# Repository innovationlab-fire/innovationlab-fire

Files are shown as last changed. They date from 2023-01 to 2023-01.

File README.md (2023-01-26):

For more detailed information about this project visit our website: https://innovationlab-fire.netlify.app

**Installation guide:**

1) To reconstruct the prototype, you need the materials listed in the following:

- Arduino R3 incl. USB-cabel
- MQ-2 Gas Sensor
- SPI Reader Micro Memory SD TF Card Memory Card Shield Module
- SIM800L GPRS GSM Module incl. antenna
- SD-Card
- Lithium Polymer Battery 3.7 V 2000 mAh
- Breadboard with 830 or 400 pins
- Sim-Card
- A Case for the hardware	(files for 3d-print available in repository)	

In addition, for the installation you need jumper wires, resistors (330 Ohm) and a soldering device. All in all, you should expect spending approximately 60 to 70 euros for the purchase of all materials for one device (as of January 2023).

2) After collecting all needed materials, you have to download the Arduino IDE. You can do that directly on the Arduino website. After successfully downloading the IDE you should also download the required library “Adafruit BusIO” by Adafruit via the integrated library manager on your Arduino IDE. Then, you can download the project code from our Github Repository.

3) After downloading the code, start your Arduino IDE and click on „File“ in the top left corner of the Arduino IDE and click on „Open…“. Then, you need to select the previously downloaded code and it will be opened in the IDE. Now, you only have to make a small alteration to the code, in order to send the SMS to the right phone number regarding your respective use case (we have made a comment like “XXXXX” to indicate where you have to change the number). After that, the code is ready to use.

4) Before starting with the hardware, create an empty csv file called "test.csv" on your SD card. This will be used later in order to save the measured gas values including the respective timestamps.

5) Regarding the hardware, you need to wire up the Arduino uno and the modules like shown in the hardware diagram below.

Circuit-diagram-SEDI

You also need to solder the sim module correctly, connect it to the separate LiPo battery and clip on the green antenna. After you have done this, see if the sim module is working correctly if it flashes every 3 seconds. If it only flashes at 1 second intervals, the sim module is still searching for the available network. As a starting aid, you can find a video concerning the wiring and soldering on our Youtube chanel: https://www.youtube.com/channel/UCS5Bbf_3bhYVp7_8QDcPbxg. Please note that the Arduino requires a constant power supply for smooth operation (5V), which can be connected via the power supply unit. Please bear in mind that we only describe the start-up via a computer, which, however, is not a realistic option for the desired application in a forest. Therefore, please inquire about alternative power supply options.

6) Once the hardware is wired and soldered correctly, you can connect the Arduino with the USB cable to the computer. Click on the „Upload“ button in the toolbar of the IDE and the code will be uploaded to the Arduino. The code will then start running and you can open the serial monitor to track the process.

7) After the code was once uploaded to the Arduino through the IDE, the Arduino will always start running the code once it has a power supply. Therefore, you can choose alternative power supply methods other than plugging it into the computer as described above.

8) In case of high gas values in the air, the device sends an SMS to the phone number you have specified. In addition, the measured values are stored on the SD card and you can visualize them by inserting the SD card into your computer via Excel according to your wishes.

**Licenses**

Our project is published under the GNU GENERAL PUBLIC LICENSE version 3 license. The full source code of the project is available on our GitHub page.

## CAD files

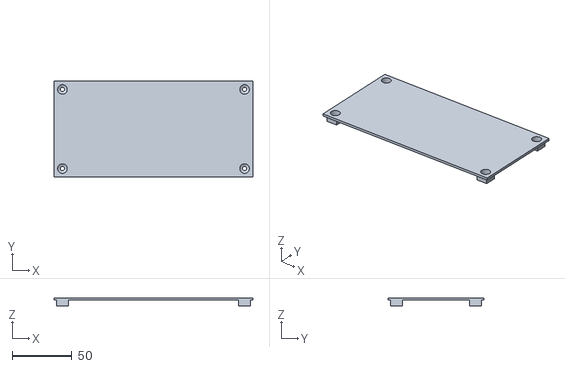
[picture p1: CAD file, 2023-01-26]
3D-Files Case/lid.stl
166.0 x 80.0 x 7.00

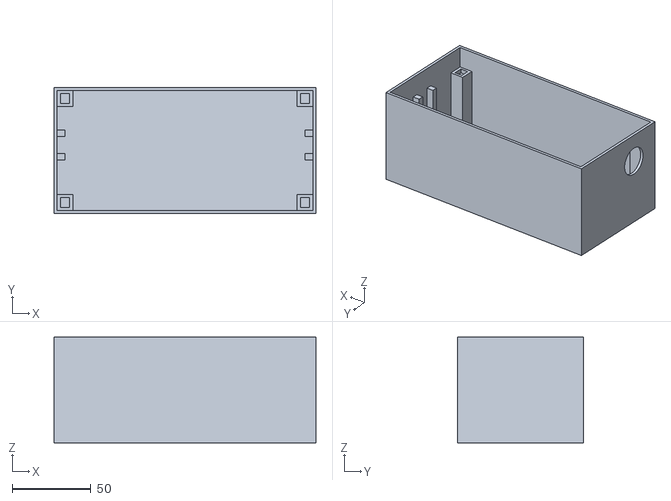
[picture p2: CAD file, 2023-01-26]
3D-Files Case/case.stl
166.0 x 80.0 x 67.0

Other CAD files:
3D-Files Case/case.ipt
3D-Files Case/lid.ipt

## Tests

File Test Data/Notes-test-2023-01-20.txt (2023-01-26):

13:40 fire start, standing close to it, only gasoline burning
13:50 close to it (1 meter), value at over 100
13:56 10 meters distance
13:59 fire is made bigger
wood burns
14:13 fire smokes, distance 3-4 m (directly at smoke value of 100 not at smoke 70-75)
14:18 1m distance
14:19 1m distance (values from 120-130)
14:22 20m distance
14:23 3m distance
14:24 1m
14:25 5m
14:27 1m
14:28 10 m
14:35-14:36 10 m
14:39 2 m
14:45 extinguishing action

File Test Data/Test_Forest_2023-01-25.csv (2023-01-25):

Date | Time | SensorValue
 | 37
23/01/25 | 16:01:04+04 | 36
23/01/25 | 16:01:08+04 | 36
23/01/25 | 16:01:11+04 | 36
23/01/25 | 16:01:14+04 | 35
23/01/25 | 16:01:18+04 | 35
23/01/25 | 16:01:21+04 | 35
23/01/25 | 16:01:24+04 | 34
23/01/25 | 16:01:28+04 | 34
23/01/25 | 16:01:31+04 | 34
23/01/25 | 16:01:34+04 | 34
23/01/25 | 16:01:38+04 | 34
23/01/25 | 16:01:41+04 | 34
23/01/25 | 16:01:45+04 | 34
23/01/25 | 16:01:48+04 | 34
23/01/25 | 16:01:51+04 | 33
23/01/25 | 16:01:55+04 | 33
23/01/25 | 16:01:58+04 | 33
23/01/25 | 16:02:01+04 | 33
23/01/25 | 16:02:05+04 | 33
23/01/25 | 16:02:08+04 | 33
23/01/25 | 16:02:11+04 | 33
23/01/25 | 16:02:15+04 | 33
23/01/25 | 16:02:18+04 | 32
23/01/25 | 16:02:21+04 | 32
23/01/25 | 16:02:25+04 | 32
23/01/25 | 16:02:28+04 | 32
23/01/25 | 16:02:31+04 | 32
23/01/25 | 16:02:35+04 | 32
23/01/25 | 16:02:38+04 | 32
23/01/25 | 16:02:41+04 | 32
23/01/25 | 16:02:45+04 | 32
23/01/25 | 16:02:48+04 | 32
23/01/25 | 16:02:51+04 | 32
23/01/25 | 16:02:55+04 | 32
23/01/25 | 16:02:58+04 | 32
23/01/25 | 16:03:01+04 | 32
23/01/25 | 16:03:05+04 | 32
23/01/25 | 16:03:08+04 | 32
23/01/25 | 16:03:11+04 | 32
23/01/25 | 16:03:15+04 | 32
23/01/25 | 16:03:18+04 | 32
23/01/25 | 16:03:22+04 | 31
23/01/25 | 16:03:25+04 | 32
23/01/25 | 16:03:28+04 | 32
23/01/25 | 16:03:32+04 | 32
23/01/25 | 16:03:35+04 | 32
23/01/25 | 16:03:38+04 | 31
23/01/25 | 16:03:42+04 | 31
23/01/25 | 16:03:45+04 | 32
23/01/25 | 16:03:48+04 | 31
23/01/25 | 16:03:52+04 | 31
23/01/25 | 16:03:55+04 | 31
23/01/25 | 16:03:58+04 | 31
23/01/25 | 16:04:02+04 | 31
23/01/25 | 16:04:05+04 | 31
23/01/25 | 16:04:08+04 | 31
23/01/25 | 16:04:12+04 | 31
23/01/25 | 16:04:15+04 | 31
23/01/25 | 16:04:19+04 | 31
23/01/25 | 16:04:22+04 | 31
23/01/25 | 16:04:25+04 | 31
23/01/25 | 16:04:29+04 | 31
23/01/25 | 16:04:32+04 | 31
23/01/25 | 16:04:35+04 | 31
23/01/25 | 16:04:39+04 | 31
23/01/25 | 16:04:42+04 | 31
23/01/25 | 16:04:45+04 | 31
23/01/25 | 16:04:49+04 | 31
23/01/25 | 16:04:52+04 | 31
23/01/25 | 16:04:55+04 | 31
23/01/25 | 16:04:59+04 | 31
23/01/25 | 16:05:02+04 | 31
23/01/25 | 16:05:05+04 | 31
23/01/25 | 16:05:09+04 | 31
23/01/25 | 16:05:12+04 | 31
23/01/25 | 16:05:15+04 | 31
23/01/25 | 16:05:19+04 | 31
23/01/25 | 16:05:22+04 | 31
23/01/25 | 16:05:25+04 | 31
23/01/25 | 16:05:29+04 | 31
23/01/25 | 16:05:32+04 | 31
23/01/25 | 16:05:35+04 | 31
23/01/25 | 16:05:39+04 | 31
23/01/25 | 16:05:42+04 | 31
23/01/25 | 16:05:45+04 | 31
23/01/25 | 16:05:49+04 | 31
23/01/25 | 16:05:52+04 | 31
23/01/25 | 16:05:56+04 | 31
23/01/25 | 16:05:59+04 | 31
23/01/25 | 16:06:02+04 | 31
23/01/25 | 16:06:06+04 | 31
23/01/25 | 16:06:09+04 | 31
23/01/25 | 16:06:12+04 | 31
23/01/25 | 16:06:16+04 | 30
23/01/25 | 16:06:19+04 | 31
23/01/25 | 16:06:22+04 | 31
23/01/25 | 16:06:26+04 | 31
23/01/25 | 16:06:29+04 | 30
23/01/25 | 16:06:32+04 | 30
23/01/25 | 16:06:36+04 | 31
23/01/25 | 16:06:39+04 | 31
23/01/25 | 16:06:42+04 | 31
23/01/25 | 16:06:46+04 | 31
23/01/25 | 16:06:49+04 | 31
23/01/25 | 16:06:52+04 | 31
23/01/25 | 16:06:56+04 | 31
23/01/25 | 16:06:59+04 | 31
23/01/25 | 16:07:02+04 | 31
23/01/25 | 16:07:06+04 | 30
23/01/25 | 16:07:09+04 | 31
23/01/25 | 16:07:12+04 | 31
23/01/25 | 16:07:16+04 | 31
23/01/25 | 16:07:19+04 | 31
23/01/25 | 16:07:22+04 | 31
23/01/25 | 16:07:26+04 | 31
23/01/25 | 16:07:29+04 | 31
23/01/25 | 16:07:32+04 | 31
23/01/25 | 16:07:36+04 | 31
23/01/25 | 16:07:39+04 | 31
23/01/25 | 16:07:43+04 | 31
23/01/25 | 16:07:46+04 | 31
23/01/25 | 16:07:49+04 | 31
23/01/25 | 16:07:53+04 | 31
23/01/25 | 16:07:56+04 | 31
23/01/25 | 16:07:59+04 | 30
23/01/25 | 16:08:03+04 | 31
23/01/25 | 16:08:06+04 | 30
23/01/25 | 16:08:09+04 | 31
23/01/25 | 16:08:13+04 | 31
23/01/25 | 16:08:16+04 | 30
23/01/25 | 16:08:19+04 | 31
23/01/25 | 16:08:23+04 | 30
23/01/25 | 16:08:26+04 | 31
23/01/25 | 16:08:29+04 | 31
23/01/25 | 16:08:33+04 | 30
23/01/25 | 16:08:36+04 | 31
23/01/25 | 16:08:39+04 | 31
23/01/25 | 16:08:43+04 | 30
23/01/25 | 16:08:46+04 | 30
23/01/25 | 16:08:49+04 | 30
23/01/25 | 16:08:53+04 | 30
23/01/25 | 16:08:56+04 | 30
23/01/25 | 16:08:59+04 | 31
23/01/25 | 16:09:03+04 | 31
23/01/25 | 16:09:06+04 | 31
23/01/25 | 16:09:10+04 | 30
23/01/25 | 16:09:13+04 | 30
23/01/25 | 16:09:16+04 | 30
23/01/25 | 16:09:20+04 | 30
23/01/25 | 16:09:23+04 | 31
23/01/25 | 16:09:26+04 | 30
23/01/25 | 16:09:30+04 | 30
23/01/25 | 16:09:33+04 | 31
23/01/25 | 16:09:36+04 | 31
23/01/25 | 16:09:40+04 | 30
23/01/25 | 16:09:43+04 | 31
23/01/25 | 16:09:46+04 | 31
23/01/25 | 16:09:50+04 | 31
23/01/25 | 16:09:53+04 | 31
23/01/25 | 16:09:56+04 | 31
23/01/25 | 16:10:00+04 | 31
23/01/25 | 16:10:03+04 | 31
23/01/25 | 16:10:06+04 | 31
23/01/25 | 16:10:10+04 | 31
23/01/25 | 16:10:13+04 | 31
23/01/25 | 16:10:16+04 | 31
23/01/25 | 16:10:20+04 | 30
23/01/25 | 16:10:23+04 | 30
23/01/25 | 16:10:26+04 | 31
23/01/25 | 16:10:30+04 | 30
23/01/25 | 16:10:33+04 | 30
23/01/25 | 16:10:36+04 | 30
23/01/25 | 16:10:40+04 | 30
23/01/25 | 16:10:43+04 | 31
23/01/25 | 16:10:46+04 | 30
23/01/25 | 16:10:50+04 | 31
23/01/25 | 16:10:53+04 | 30
23/01/25 | 16:10:57+04 | 31
23/01/25 | 16:11:00+04 | 30
23/01/25 | 16:11:03+04 | 30
23/01/25 | 16:11:07+04 | 30
23/01/25 | 16:11:10+04 | 30
23/01/25 | 16:11:13+04 | 30
23/01/25 | 16:11:17+04 | 30
23/01/25 | 16:11:20+04 | 30
23/01/25 | 16:11:23+04 | 30
23/01/25 | 16:11:27+04 | 30
23/01/25 | 16:11:30+04 | 30
23/01/25 | 16:11:33+04 | 31
23/01/25 | 16:11:37+04 | 30
23/01/25 | 16:11:40+04 | 30
23/01/25 | 16:11:43+04 | 30
23/01/25 | 16:11:47+04 | 30
23/01/25 | 16:11:50+04 | 30
23/01/25 | 16:11:53+04 | 30
23/01/25 | 16:11:57+04 | 30
23/01/25 | 16:12:00+04 | 30
23/01/25 | 16:12:03+04 | 30
23/01/25 | 16:12:07+04 | 30
23/01/25 | 16:12:10+04 | 30
23/01/25 | 16:12:13+04 | 30
23/01/25 | 16:12:17+04 | 30
23/01/25 | 16:12:20+04 | 30
23/01/25 | 16:12:24+04 | 30
23/01/25 | 16:12:27+04 | 30
23/01/25 | 16:12:30+04 | 30
23/01/25 | 16:12:34+04 | 30
23/01/25 | 16:12:37+04 | 30
23/01/25 | 16:12:40+04 | 30
23/01/25 | 16:12:44+04 | 30
23/01/25 | 16:12:47+04 | 30
23/01/25 | 16:12:50+04 | 30
23/01/25 | 16:12:54+04 | 30
23/01/25 | 16:12:57+04 | 30
23/01/25 | 16:13:00+04 | 31
23/01/25 | 16:13:04+04 | 30
23/01/25 | 16:13:07+04 | 30
23/01/25 | 16:13:10+04 | 31
23/01/25 | 16:13:14+04 | 30
23/01/25 | 16:13:17+04 | 30
23/01/25 | 16:13:20+04 | 30
23/01/25 | 16:13:24+04 | 30
23/01/25 | 16:13:27+04 | 30
23/01/25 | 16:13:30+04 | 30
23/01/25 | 16:13:34+04 | 30
23/01/25 | 16:13:37+04 | 30
23/01/25 | 16:13:40+04 | 30
23/01/25 | 16:13:44+04 | 30
23/01/25 | 16:13:47+04 | 30
23/01/25 | 16:13:50+04 | 30
23/01/25 | 16:13:54+04 | 30
23/01/25 | 16:13:57+04 | 30
23/01/25 | 16:14:00+04 | 30
23/01/25 | 16:14:04+04 | 30
23/01/25 | 16:14:07+04 | 30
23/01/25 | 16:14:11+04 | 30
23/01/25 | 16:14:14+04 | 30
23/01/25 | 16:14:17+04 | 30
23/01/25 | 16:14:21+04 | 30
23/01/25 | 16:14:24+04 | 30
23/01/25 | 16:14:27+04 | 30
23/01/25 | 16:14:31+04 | 30
23/01/25 | 16:14:34+04 | 30
23/01/25 | 16:14:37+04 | 30
23/01/25 | 16:14:41+04 | 30
23/01/25 | 16:14:44+04 | 30
23/01/25 | 16:14:47+04 | 30
23/01/25 | 16:14:51+04 | 30
23/01/25 | 16:14:54+04 | 30
23/01/25 | 16:14:57+04 | 30
23/01/25 | 16:15:01+04 | 30
23/01/25 | 16:15:04+04 | 30
23/01/25 | 16:15:07+04 | 30
23/01/25 | 16:15:11+04 | 30
23/01/25 | 16:15:14+04 | 30
23/01/25 | 16:15:17+04 | 30
23/01/25 | 16:15:21+04 | 30
23/01/25 | 16:15:24+04 | 30
23/01/25 | 16:15:27+04 | 30
23/01/25 | 16:15:31+04 | 30
23/01/25 | 16:15:34+04 | 30
23/01/25 | 16:15:37+04 | 30
23/01/25 | 16:15:41+04 | 30
23/01/25 | 16:15:44+04 | 30
23/01/25 | 16:15:48+04 | 30
23/01/25 | 16:15:51+04 | 30
23/01/25 | 16:15:54+04 | 30
23/01/25 | 16:15:58+04 | 30
23/01/25 | 16:16:01+04 | 30
23/01/25 | 16:16:04+04 | 30
23/01/25 | 16:16:08+04 | 30
23/01/25 | 16:16:11+04 | 30
23/01/25 | 16:16:14+04 | 30
23/01/25 | 16:16:18+04 | 30
23/01/25 | 16:16:21+04 | 30
23/01/25 | 16:16:24+04 | 30
23/01/25 | 16:16:28+04 | 30
23/01/25 | 16:16:31+04 | 30
23/01/25 | 16:16:34+04 | 30
23/01/25 | 16:16:38+04 | 30
23/01/25 | 16:16:41+04 | 30
23/01/25 | 16:16:44+04 | 31
23/01/25 | 16:16:48+04 | 30
23/01/25 | 16:16:51+04 | 30
23/01/25 | 16:16:54+04 | 30
23/01/25 | 16:16:58+04 | 30
23/01/25 | 16:17:01+04 | 31
23/01/25 | 16:17:04+04 | 30
23/01/25 | 16:17:08+04 | 30
23/01/25 | 16:17:11+04 | 30
23/01/25 | 16:17:14+04 | 30
23/01/25 | 16:17:18+04 | 31
23/01/25 | 16:17:21+04 | 30
23/01/25 | 16:17:25+04 | 30
23/01/25 | 16:17:28+04 | 30
23/01/25 | 16:17:31+04 | 30
23/01/25 | 16:17:35+04 | 30
23/01/25 | 16:17:38+04 | 30
23/01/25 | 16:17:41+04 | 30
23/01/25 | 16:17:45+04 | 30
23/01/25 | 16:17:48+04 | 30
23/01/25 | 16:17:51+04 | 30
23/01/25 | 16:17:55+04 | 30
23/01/25 | 16:17:58+04 | 30
23/01/25 | 16:18:01+04 | 30
23/01/25 | 16:18:05+04 | 30
23/01/25 | 16:18:08+04 | 30
23/01/25 | 16:18:11+04 | 30
23/01/25 | 16:18:15+04 | 30
23/01/25 | 16:18:18+04 | 30
23/01/25 | 16:18:21+04 | 30
23/01/25 | 16:18:25+04 | 31
23/01/25 | 16:18:28+04 | 30
23/01/25 | 16:18:31+04 | 30
23/01/25 | 16:18:35+04 | 30
23/01/25 | 16:18:38+04 | 30
23/01/25 | 16:18:41+04 | 30
23/01/25 | 16:18:45+04 | 30
23/01/25 | 16:18:48+04 | 30
23/01/25 | 16:18:51+04 | 30
23/01/25 | 16:18:55+04 | 30
23/01/25 | 16:18:58+04 | 30
23/01/25 | 16:19:02+04 | 30
23/01/25 | 16:19:05+04 | 30
23/01/25 | 16:19:08+04 | 30
23/01/25 | 16:19:12+04 | 30
23/01/25 | 16:19:15+04 | 30
23/01/25 | 16:19:18+04 | 30
23/01/25 | 16:19:22+04 | 30
23/01/25 | 16:19:25+04 | 30
23/01/25 | 16:19:28+04 | 30
23/01/25 | 16:19:32+04 | 30
23/01/25 | 16:19:35+04 | 30
23/01/25 | 16:19:38+04 | 30
23/01/25 | 16:19:42+04 | 30
23/01/25 | 16:19:45+04 | 30
23/01/25 | 16:19:48+04 | 30
23/01/25 | 16:19:52+04 | 30
23/01/25 | 16:19:55+04 | 30
23/01/25 | 16:19:58+04 | 30
23/01/25 | 16:20:02+04 | 30
23/01/25 | 16:20:05+04 | 30
23/01/25 | 16:20:08+04 | 30
23/01/25 | 16:20:12+04 | 30
23/01/25 | 16:20:15+04 | 30
23/01/25 | 16:20:18+04 | 30
23/01/25 | 16:20:22+04 | 30
23/01/25 | 16:20:25+04 | 30
23/01/25 | 16:20:28+04 | 30
23/01/25 | 16:20:32+04 | 30
23/01/25 | 16:20:35+04 | 30
23/01/25 | 16:20:39+04 | 30
23/01/25 | 16:20:42+04 | 30
23/01/25 | 16:20:45+04 | 30
23/01/25 | 16:20:49+04 | 30
23/01/25 | 16:20:52+04 | 30
23/01/25 | 16:20:55+04 | 30
23/01/25 | 16:20:59+04 | 30
23/01/25 | 16:21:02+04 | 30
23/01/25 | 16:21:05+04 | 30
23/01/25 | 16:21:09+04 | 30
23/01/25 | 16:21:12+04 | 30
23/01/25 | 16:21:15+04 | 30
23/01/25 | 16:21:19+04 | 30
23/01/25 | 16:21:22+04 | 30
23/01/25 | 16:21:25+04 | 30
23/01/25 | 16:21:29+04 | 30
23/01/25 | 16:21:32+04 | 30
23/01/25 | 16:21:35+04 | 30
23/01/25 | 16:21:39+04 | 30
23/01/25 | 16:21:42+04 | 30
23/01/25 | 16:21:45+04 | 30
23/01/25 | 16:21:49+04 | 30
23/01/25 | 16:21:52+04 | 30
23/01/25 | 16:21:55+04 | 30
23/01/25 | 16:21:59+04 | 30
23/01/25 | 16:22:02+04 | 30
23/01/25 | 16:22:06+04 | 30
23/01/25 | 16:22:09+04 | 30
23/01/25 | 16:22:12+04 | 30
23/01/25 | 16:22:16+04 | 30
23/01/25 | 16:22:19+04 | 30
23/01/25 | 16:22:22+04 | 30
23/01/25 | 16:22:26+04 | 30
23/01/25 | 16:22:29+04 | 30
23/01/25 | 16:22:32+04 | 30
23/01/25 | 16:22:36+04 | 30
23/01/25 | 16:22:39+04 | 30
23/01/25 | 16:22:42+04 | 30
23/01/25 | 16:22:46+04 | 30
23/01/25 | 16:22:49+04 | 30
23/01/25 | 16:22:52+04 | 30
23/01/25 | 16:22:56+04 | 30
23/01/25 | 16:22:59+04 | 30
23/01/25 | 16:23:02+04 | 30
23/01/25 | 16:23:06+04 | 30
23/01/25 | 16:23:09+04 | 30
23/01/25 | 16:23:12+04 | 30
23/01/25 | 16:23:16+04 | 30
23/01/25 | 16:23:19+04 | 30
23/01/25 | 16:23:22+04 | 30
23/01/25 | 16:23:26+04 | 30
23/01/25 | 16:23:29+04 | 30
23/01/25 | 16:23:32+04 | 30
23/01/25 | 16:23:36+04 | 30
23/01/25 | 16:23:39+04 | 30
23/01/25 | 16:23:43+04 | 30
23/01/25 | 16:23:46+04 | 30
23/01/25 | 16:23:49+04 | 30
23/01/25 | 16:23:53+04 | 30
23/01/25 | 16:23:56+04 | 30
23/01/25 | 16:23:59+04 | 30
23/01/25 | 16:24:03+04 | 30
23/01/25 | 16:24:06+04 | 30
23/01/25 | 16:24:09+04 | 30
23/01/25 | 16:24:13+04 | 31
23/01/25 | 16:24:16+04 | 30
23/01/25 | 16:24:19+04 | 30
23/01/25 | 16:24:23+04 | 30
23/01/25 | 16:24:26+04 | 30
23/01/25 | 16:24:29+04 | 30
23/01/25 | 16:24:33+04 | 30
23/01/25 | 16:24:36+04 | 30
23/01/25 | 16:24:39+04 | 30
23/01/25 | 16:24:43+04 | 30
23/01/25 | 16:24:46+04 | 30
23/01/25 | 16:24:49+04 | 30
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

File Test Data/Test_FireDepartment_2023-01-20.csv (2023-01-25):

Date,Time,SensorValue
23/01/20,12:51:23, 116.00
23/01/20,12:51:25, 157.00
23/01/20,12:51:27, 206.00
23/01/20,12:51:29, 231.00
23/01/20,12:51:31, 237.00
23/01/20,12:51:33, 234.00
23/01/20,12:51:35, 212.00
23/01/20,12:51:37, 207.00
23/01/20,12:51:39, 215.00
23/01/20,12:51:41, 202.00
23/01/20,12:51:43, 210.00
23/01/20,12:51:45, 192.00
23/01/20,12:51:47, 193.00
23/01/20,12:51:49, 177.00
23/01/20,12:51:51, 179.00
23/01/20,12:51:53, 172.00
23/01/20,12:51:55, 173.00
23/01/20,12:51:57, 163.00
23/01/20,12:51:59, 160.00
23/01/20,12:52:01, 163.00
23/01/20,12:52:03, 158.00
23/01/20,12:52:05, 129.00
23/01/20,12:52:07, 150.00
23/01/20,12:52:09, 153.00
23/01/20,12:52:11, 126.00
23/01/20,12:52:13, 133.00
23/01/20,12:52:15, 147.00
23/01/20,12:52:17, 138.00
23/01/20,12:52:19, 132.00
23/01/20,12:52:21, 132.00
23/01/20,12:52:23, 135.00
23/01/20,12:52:25, 138.00
23/01/20,12:52:27, 133.00
23/01/20,12:52:29, 130.00
23/01/20,12:52:31, 127.00
23/01/20,12:52:33, 128.00
23/01/20,12:52:35, 126.00
23/01/20,12:52:37, 123.00
23/01/20,12:52:39, 122.00
23/01/20,12:52:41, 121.00
23/01/20,12:52:43, 120.00
23/01/20,12:52:45, 110.00
23/01/20,12:52:47, 121.00
23/01/20,12:52:49, 119.00
23/01/20,12:52:51, 119.00
23/01/20,12:52:53, 111.00
23/01/20,12:52:55, 106.00
23/01/20,12:52:57, 104.00
23/01/20,12:52:59, 102.00
23/01/20,12:53:01, 102.00
23/01/20,12:53:03, 101.00
23/01/20,12:53:05, 101.00
23/01/20,12:53:07, 100.00
23/01/20,12:53:09, 100.00
23/01/20,12:53:11, 100.00
23/01/20,12:53:13, 99.00
23/01/20,12:53:15, 99.00
23/01/20,12:53:17, 101.00
23/01/20,12:53:19, 101.00
23/01/20,12:53:21, 99.00
23/01/20,12:53:23, 99.00
23/01/20,12:53:25, 101.00
23/01/20,12:53:27, 107.00
23/01/20,12:53:29, 88.00
23/01/20,12:53:31, 91.00
23/01/20,12:53:33, 82.00
23/01/20,12:53:35, 77.00
23/01/20,12:53:37, 79.00
23/01/20,12:53:39, 79.00
23/01/20,12:53:41, 78.00
23/01/20,12:53:43, 80.00
23/01/20,12:53:45, 80.00
23/01/20,12:53:47, 80.00
23/01/20,12:53:49, 103.00
23/01/20,12:53:51, 90.00
23/01/20,12:53:53, 84.00
23/01/20,12:53:55, 84.00
23/01/20,12:53:57, 79.00
23/01/20,12:53:59, 82.00
23/01/20,12:54:01, 78.00
23/01/20,12:54:03, 64.00
23/01/20,12:54:05, 61.00
23/01/20,12:54:07, 62.00
23/01/20,12:54:09, 63.00
23/01/20,12:54:11, 59.00
23/01/20,12:54:13, 76.00
23/01/20,12:54:15, 77.00
23/01/20,12:54:17, 57.00
23/01/20,12:54:19, 74.00
23/01/20,12:54:21, 74.00
23/01/20,12:54:23, 74.00
23/01/20,12:54:25, 56.00
23/01/20,12:54:27, 55.00
23/01/20,12:54:29, 55.00
23/01/20,12:54:31, 55.00
23/01/20,12:54:33, 55.00
23/01/20,12:54:35, 55.00
23/01/20,12:54:37, 55.00
23/01/20,12:54:39, 56.00
23/01/20,12:54:41, 58.00
23/01/20,12:54:43, 73.00
23/01/20,12:54:45, 52.00
23/01/20,12:54:47, 52.00
23/01/20,12:54:49, 52.00
23/01/20,12:54:51, 53.00
23/01/20,12:54:53, 53.00
23/01/20,12:54:55, 54.00
23/01/20,12:54:57, 53.00
23/01/20,12:54:59, 59.00
23/01/20,12:55:01, 52.00
23/01/20,12:55:03, 56.00
23/01/20,12:55:05, 121.00
23/01/20,12:55:07, 102.00
23/01/20,12:55:09, 99.00
23/01/20,12:55:11, 95.00
23/01/20,12:55:13, 96.00
23/01/20,12:55:15, 107.00
23/01/20,12:55:17, 98.00
23/01/20,12:55:19, 99.00
23/01/20,12:55:21, 100.00
23/01/20,12:55:23, 90.00
23/01/20,12:55:25, 92.00
23/01/20,12:55:27, 94.00
23/01/20,12:55:29, 94.00
23/01/20,12:55:31, 72.00
23/01/20,12:55:33, 80.00
23/01/20,12:55:35, 102.00
23/01/20,12:55:37, 95.00
23/01/20,12:55:39, 94.00
23/01/20,12:55:41, 93.00
23/01/20,12:55:43, 101.00
23/01/20,12:55:45, 82.00
23/01/20,12:55:47, 84.00
23/01/20,12:55:49, 85.00
23/01/20,12:55:51, 85.00
23/01/20,12:55:53, 96.00
23/01/20,12:55:55, 109.00
23/01/20,12:55:57, 95.00
23/01/20,12:55:59, 92.00
23/01/20,12:56:01, 94.00
23/01/20,12:56:03, 93.00
23/01/20,12:56:05, 90.00
23/01/20,12:56:07, 91.00
23/01/20,12:56:09, 77.00
23/01/20,12:56:11, 94.00
23/01/20,12:56:13, 102.00
23/01/20,12:56:15, 74.00
23/01/20,12:56:17, 68.00
23/01/20,12:56:19, 78.00
23/01/20,12:56:21, 88.00
23/01/20,12:56:23, 98.00
23/01/20,12:56:25, 89.00
23/01/20,12:56:27, 100.00
23/01/20,12:56:29, 99.00
23/01/20,12:56:31, 64.00
23/01/20,12:56:33, 65.00
23/01/20,12:56:35, 75.00
23/01/20,12:56:37, 79.00
23/01/20,12:56:39, 97.00
23/01/20,12:56:41, 86.00
23/01/20,12:56:43, 112.00
23/01/20,12:56:45, 69.00
23/01/20,12:56:47, 78.00
23/01/20,12:56:49, 75.00
23/01/20,12:56:51, 81.00
23/01/20,12:56:53, 77.00
23/01/20,12:56:55, 76.00
23/01/20,12:56:57, 79.00
23/01/20,12:56:59, 77.00
23/01/20,12:57:01, 82.00
23/01/20,12:57:03, 78.00
23/01/20,12:57:05, 69.00
23/01/20,12:57:07, 81.00
23/01/20,12:57:09, 78.00
23/01/20,12:57:11, 78.00
23/01/20,12:57:13, 82.00
23/01/20,12:57:15, 77.00
23/01/20,12:57:17, 69.00
23/01/20,12:57:19, 68.00
23/01/20,12:57:21, 68.00
23/01/20,12:57:23, 56.00
23/01/20,12:57:25, 78.00
23/01/20,12:57:27, 67.00
23/01/20,12:57:29, 65.00
23/01/20,12:57:31, 88.00
23/01/20,12:57:33, 109.00
23/01/20,12:57:35, 72.00
23/01/20,12:57:37, 88.00
23/01/20,12:57:39, 73.00
23/01/20,12:57:41, 70.00
23/01/20,12:57:43, 74.00
23/01/20,12:57:45, 73.00
23/01/20,12:57:47, 72.00
23/01/20,12:57:49, 91.00
23/01/20,12:57:51, 90.00
23/01/20,12:57:53, 106.00
23/01/20,12:57:55, 102.00
23/01/20,12:57:57, 100.00
23/01/20,12:57:59, 91.00
23/01/20,12:58:01, 93.00
23/01/20,12:58:03, 90.00
23/01/20,12:58:05, 86.00
23/01/20,12:58:07, 89.00
23/01/20,12:58:09, 109.00
23/01/20,12:58:11, 73.00
23/01/20,12:58:13, 71.00
23/01/20,12:58:15, 70.00
23/01/20,12:58:17, 75.00
23/01/20,12:58:19, 71.00
23/01/20,12:58:21, 67.00
23/01/20,12:58:23, 68.00
23/01/20,12:58:25, 66.00
23/01/20,12:58:27, 65.00
23/01/20,12:58:29, 66.00
23/01/20,12:58:31, 71.00
23/01/20,12:58:33, 69.00
23/01/20,12:58:35, 67.00
23/01/20,12:58:37, 68.00
23/01/20,12:58:39, 70.00
23/01/20,12:58:41, 69.00
23/01/20,12:58:43, 69.00
23/01/20,12:58:45, 69.00
23/01/20,12:58:47, 68.00
23/01/20,12:58:49, 71.00
23/01/20,12:58:51, 68.00
23/01/20,12:58:53, 69.00
23/01/20,12:58:55, 68.00
23/01/20,12:58:57, 68.00
23/01/20,12:58:59, 79.00
23/01/20,12:59:01, 68.00
23/01/20,12:59:03, 70.00
23/01/20,12:59:05, 70.00
23/01/20,12:59:07, 70.00
23/01/20,12:59:09, 69.00
23/01/20,12:59:11, 69.00
23/01/20,12:59:13, 68.00
23/01/20,12:59:15, 70.00
23/01/20,12:59:17, 76.00
23/01/20,12:59:19, 90.00
23/01/20,12:59:21, 76.00
23/01/20,12:59:23, 73.00
23/01/20,12:59:25, 67.00
23/01/20,12:59:27, 74.00
23/01/20,12:59:29, 66.00
23/01/20,12:59:31, 64.00
23/01/20,12:59:33, 71.00
23/01/20,12:59:35, 83.00
23/01/20,12:59:37, 84.00
23/01/20,12:59:39, 71.00
23/01/20,12:59:41, 77.00
23/01/20,12:59:43, 76.00
23/01/20,12:59:45, 75.00
23/01/20,12:59:47, 71.00
23/01/20,12:59:49, 82.00
23/01/20,12:59:51, 59.00
23/01/20,12:59:53, 73.00
23/01/20,12:59:55, 68.00
23/01/20,12:59:57, 65.00
23/01/20,12:59:59, 63.00
23/01/20,13:00:01, 58.00
23/01/20,13:00:03, 61.00
23/01/20,13:00:05, 61.00
23/01/20,13:00:07, 59.00
23/01/20,13:00:09, 60.00
23/01/20,13:00:11, 60.00
23/01/20,13:00:13, 62.00
23/01/20,13:00:15, 56.00
23/01/20,13:00:17, 63.00
23/01/20,13:00:19, 70.00
23/01/20,13:00:21, 72.00
23/01/20,13:00:23, 66.00
23/01/20,13:00:25, 64.00
23/01/20,13:00:27, 56.00
23/01/20,13:00:29, 56.00
23/01/20,13:00:31, 56.00
23/01/20,13:00:33, 54.00
23/01/20,13:00:35, 55.00
23/01/20,13:00:37, 54.00
23/01/20,13:00:39, 55.00
23/01/20,13:00:41, 57.00
23/01/20,13:00:43, 57.00
23/01/20,13:00:45, 55.00
23/01/20,13:00:47, 56.00
23/01/20,13:00:49, 58.00
23/01/20,13:00:51, 58.00
23/01/20,13:00:53, 59.00
23/01/20,13:00:55, 58.00
23/01/20,13:00:57, 85.00
23/01/20,13:00:59, 101.00
23/01/20,13:01:01, 88.00
23/01/20,13:01:03, 97.00
23/01/20,13:01:05, 89.00
23/01/20,13:01:07, 88.00
23/01/20,13:01:09, 68.00
23/01/20,13:01:11, 73.00
23/01/20,13:01:13, 73.00
23/01/20,13:01:15, 74.00
23/01/20,13:01:17, 73.00
23/01/20,13:01:19, 71.00
23/01/20,13:01:21, 70.00
23/01/20,13:01:23, 73.00
23/01/20,13:01:25, 74.00
23/01/20,13:01:27, 74.00
23/01/20,13:01:29, 72.00
23/01/20,13:01:31, 73.00
23/01/20,13:01:33, 85.00
23/01/20,13:01:35, 71.00
23/01/20,13:01:37, 70.00
23/01/20,13:01:39, 65.00
23/01/20,13:01:41, 65.00
23/01/20,13:01:43, 66.00
23/01/20,13:01:45, 68.00
23/01/20,13:01:47, 64.00
23/01/20,13:01:49, 67.00
23/01/20,13:01:51, 66.00
23/01/20,13:01:53, 70.00
23/01/20,13:01:55, 63.00
23/01/20,13:01:57, 67.00
23/01/20,13:01:59, 72.00
23/01/20,13:02:01, 69.00
23/01/20,13:02:03, 59.00
23/01/20,13:02:05, 62.00
23/01/20,13:02:07, 52.00
23/01/20,13:02:09, 54.00
23/01/20,13:02:11, 54.00
23/01/20,13:02:13, 55.00
23/01/20,13:02:15, 56.00
23/01/20,13:02:17, 56.00
23/01/20,13:02:19, 54.00
23/01/20,13:02:21, 54.00
23/01/20,13:02:23, 56.00
23/01/20,13:02:25, 55.00
23/01/20,13:02:27, 54.00
23/01/20,13:02:29, 55.00
23/01/20,13:02:31, 61.00
23/01/20,13:02:33, 64.00
23/01/20,13:02:35, 64.00
23/01/20,13:02:37, 60.00
23/01/20,13:02:39, 65.00
23/01/20,13:02:41, 68.00
23/01/20,13:02:43, 65.00
23/01/20,13:02:45, 68.00
23/01/20,13:02:47, 61.00
23/01/20,13:02:49, 78.00
23/01/20,13:02:51, 64.00
23/01/20,13:02:53, 64.00
23/01/20,13:02:55, 66.00
23/01/20,13:02:57, 65.00
23/01/20,13:02:59, 62.00
23/01/20,13:03:01, 62.00
23/01/20,13:03:03, 61.00
23/01/20,13:03:05, 65.00
23/01/20,13:03:07, 71.00
23/01/20,13:03:09, 68.00
23/01/20,13:03:11, 63.00
23/01/20,13:03:13, 64.00
23/01/20,13:03:15, 63.00
23/01/20,13:03:17, 61.00
23/01/20,13:03:19, 57.00
23/01/20,13:03:21, 62.00
23/01/20,13:03:23, 54.00
23/01/20,13:03:25, 56.00
23/01/20,13:03:27, 58.00
23/01/20,13:03:29, 56.00
23/01/20,13:03:31, 63.00
23/01/20,13:03:33, 63.00
23/01/20,13:03:35, 57.00
23/01/20,13:03:37, 61.00
23/01/20,13:03:39, 61.00
23/01/20,13:03:41, 59.00
23/01/20,13:03:43, 58.00
23/01/20,13:03:45, 57.00
23/01/20,13:03:47, 57.00
23/01/20,13:03:49, 64.00
23/01/20,13:03:51, 58.00
23/01/20,13:03:53, 64.00
23/01/20,13:03:55, 55.00
23/01/20,13:03:57, 48.00
23/01/20,13:03:59, 62.00
23/01/20,13:04:01, 66.00
23/01/20,13:04:03, 63.00
23/01/20,13:04:05, 67.00
23/01/20,13:04:07, 64.00
23/01/20,13:04:09, 53.00
23/01/20,13:04:11, 65.00
23/01/20,13:04:13, 54.00
23/01/20,13:04:15, 60.00
23/01/20,13:04:17, 52.00
23/01/20,13:04:19, 54.00
23/01/20,13:04:21, 46.00
23/01/20,13:04:23, 48.00
23/01/20,13:04:25, 45.00
23/01/20,13:04:27, 49.00
23/01/20,13:04:29, 48.00
23/01/20,13:04:31, 59.00
23/01/20,13:04:33, 63.00
23/01/20,13:04:35, 75.00
23/01/20,13:04:37, 67.00
23/01/20,13:04:39, 56.00
23/01/20,13:04:41, 69.00
23/01/20,13:04:43, 61.00
23/01/20,13:04:45, 62.00
23/01/20,13:04:47, 68.00
23/01/20,13:04:49, 52.00
23/01/20,13:04:51, 54.00
23/01/20,13:04:53, 64.00
23/01/20,13:04:55, 57.00
23/01/20,13:04:57, 55.00
23/01/20,13:04:59, 65.00
23/01/20,13:05:01, 68.00
23/01/20,13:05:03, 67.00
23/01/20,13:05:05, 65.00
23/01/20,13:05:07, 58.00
23/01/20,13:05:09, 66.00
23/01/20,13:05:11, 60.00
23/01/20,13:05:13, 56.00
23/01/20,13:05:15, 64.00
23/01/20,13:05:17, 60.00
23/01/20,13:05:19, 65.00
23/01/20,13:05:21, 55.00
23/01/20,13:05:23, 65.00
23/01/20,13:05:25, 54.00
23/01/20,13:05:27, 57.00
23/01/20,13:05:29, 67.00
23/01/20,13:05:31, 66.00
23/01/20,13:05:33, 63.00
23/01/20,13:05:35, 66.00
23/01/20,13:05:37, 60.00
23/01/20,13:05:39, 57.00
23/01/20,13:05:41, 52.00
23/01/20,13:05:43, 64.00
23/01/20,13:05:45, 61.00
23/01/20,13:05:47, 63.00
23/01/20,13:05:49, 59.00
23/01/20,13:05:51, 66.00
23/01/20,13:05:53, 54.00
23/01/20,13:05:55, 69.00
23/01/20,13:05:57, 63.00
23/01/20,13:05:59, 71.00
23/01/20,13:06:01, 52.00
23/01/20,13:06:03, 59.00
23/01/20,13:06:05, 58.00
23/01/20,13:06:07, 64.00
23/01/20,13:06:09, 71.00
23/01/20,13:06:11, 68.00
23/01/20,13:06:13, 59.00
23/01/20,13:06:15, 64.00
23/01/20,13:06:17, 59.00
23/01/20,13:06:19, 59.00
23/01/20,13:06:21, 68.00
23/01/20,13:06:23, 71.00
23/01/20,13:06:25, 63.00
23/01/20,13:06:27, 64.00
23/01/20,13:06:29, 64.00
23/01/20,13:06:31, 67.00
23/01/20,13:06:33, 58.00
23/01/20,13:06:35, 55.00
23/01/20,13:06:37, 63.00
23/01/20,13:06:39, 63.00
23/01/20,13:06:41, 60.00
23/01/20,13:06:43, 60.00
23/01/20,13:06:45, 64.00
23/01/20,13:06:47, 60.00
23/01/20,13:06:49, 46.00
23/01/20,13:06:51, 66.00
23/01/20,13:06:53, 65.00
23/01/20,13:06:55, 46.00
23/01/20,13:06:57, 55.00
23/01/20,13:06:59, 55.00
23/01/20,13:07:01, 64.00
23/01/20,13:07:03, 55.00
23/01/20,13:07:05, 73.00
23/01/20,13:07:07, 97.00
23/01/20,13:07:09, 95.00
23/01/20,13:07:11, 103.00
23/01/20,13:07:13, 102.00
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

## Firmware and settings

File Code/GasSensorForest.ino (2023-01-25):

#include <SD.h>
#include <SPI.h>
#include <SoftwareSerial.h>

#define Threshold 80 // A fire is indicated from this value.

SoftwareSerial GSM(7, 8); //SIM800L Tx & Rx is connected to Arduino #7 & #8

#define MQ2pin 0
// Variables
String fileName = "/test.csv"; // PUT THE NAME OF THE FILE ON YOUR SD CARD HERE
const char number[] = "+XXXXXXXXXXXXX"; // PUT YOUR PHONE NUMBER HERE WITH THE CORRESPONDING COUNTRY CODE

File myFile;
int counter =0; // Counter for sensor values above threshold
int counterThreshold = 20; // Threshold to catch false positives

char text[100];
String timeStamp;
bool error; 
bool sent = false;

int sensorValue;  // This value indicates Rs/Ro
const unsigned int wt_ms = 200; // Wait ms
// Methods
void initSD(){ //Initializes SD Card Module

  Serial.print("Initializing SD-Card: ");

  if(!SD.begin(10)) {
    Serial.println("SD Card initialization failed");
    while(1);
  }

  Serial.println("SD Card initialization successful");
}

void writeSDHeader() { //Writes Headers into SD File
  myFile = SD.open(fileName, FILE_WRITE);

  if(myFile) {
    Serial.println("--------------------------\n");
    Serial.print("Writing to csv file: ");

    myFile.println("Date,Time,SensorValue");

    myFile.close();
  }
  else {
    Serial.println("error opening csv file");
  }
}

void writeSDData() { //Writes the recieved values in a CSV with timestamp and the respective value
  myFile = SD.open(fileName, FILE_WRITE);

  if(myFile) {
    myFile.print(timeStamp);
    myFile.print(", ");
    myFile.print(sensorValue);
    myFile.println();

    myFile.close();
  }
  else if (!myFile) {
    Serial.println("error opening csv file");
  }
}

void getTime() { // Gets the timestamp vom GSM module and crops the string to the needed format
  GSM.println("AT+CCLK?");
  timeStamp = "";
  delay(200);
  if(GSM.available()) {
    timeStamp = GSM.readString();
    delay(100);
  }
  timeStamp.remove(0, 19);
  timeStamp.trim();
  timeStamp.remove(20);
  timeStamp.trim();
  return timeStamp;
}

void updateSerial(unsigned int wait_ms){ // Needed for communication with the SIM Module
  String dataString = "";
  delay(wait_ms);
  if(GSM.available()) {
    dataString = GSM.readString();
    Serial.println(dataString);
  }
  while(Serial.available()) {
    GSM.write(Serial.read());
  }
}

void initSIM() { //Initializes SIM Module

  GSM.begin(9600);

  GSM.println("AT"); //SIM_Modul Handshake test.
  updateSerial(wt_ms);

  GSM.println("AT+CLTS = 1"); // Make the SIM Module log the time
  updateSerial(wt_ms);

  GSM.println("AT&W"); // Copy the last input so timelogging statis is not lost on restart.
  updateSerial(wt_ms);

  GSM.println("AT+CFUN=1,1"); // Restart the SIM Module so the timelogging can work
  updateSerial(wt_ms);

  GSM.println("AT"); //SIM_Modul Handshake test.
  updateSerial(wt_ms);

  delay(10);

  GSM.println("AT+CSQ"); //Signal quality test, value range is 0-31 , 31 is the best
  updateSerial(wt_ms);

  delay(10);	

  GSM.println("AT+CCID"); //Read SIM information to confirm whether the SIM is plugged
  updateSerial(wt_ms);

  delay(10);

  GSM.println("AT+CREG?"); //Check whether it has registered in the network
  updateSerial(wt_ms);

  GSM.println("AT+CLTS = 1"); 
  updateSerial(wt_ms);

  delay(10);

  GSM.println("AT+CCLK?"); // Requests Time
  updateSerial(wt_ms);

}

void sleepSIM() { // Sets SIM Module in Sleep Mode
  GSM.println("AT+CSCLK=2");
  updateSerial(wt_ms);
  delay(6000);
  Serial.println("SIM_Module in temporary sleep mode");
}

void allWorkingSMS () { // Sends an SMS once everything is set up correctly and all modules are initialized.GSM.begin(9600);
  GSM.begin(9600);
  GSM.println("AT"); //Command to wake up SIM_Module
  updateSerial(wt_ms);
  GSM.println("AT+CMGF=1"); // Configuring TEXT mode
  updateSerial(wt_ms);
  GSM.println("AT+CMGS=\""+String(number)+"\""); 
  updateSerial(wt_ms);
  GSM.print("All Modules have been correctly initialized and the Gas Sensor is warmed up. Forrest Fire Alarm is now live!");
  GSM.write(26);
  GSM.println("");
  updateSerial(wt_ms);
}

//Code
void setup() {

	Serial.begin(9600);
	delay(3600000);  // Warmup delay, best to be around an hour

  Serial.println("Warmed up.");

  initSIM(); 
  //sleepSIM();

  initSD();
  writeSDHeader();
  delay(2000);

  allWorkingSMS();

  delay(5000);
}

void loop() {

  getTime();  //Get the timestamp
  Serial.println(timeStamp);

  sensorValue = analogRead(MQ2pin); //Read value from MQ2 sensor
  
  Serial.print("Sensor Value: ");
  Serial.println(sensorValue);
  writeSDData(); //Writes sensor value and timestamp in CSV

  if(sensorValue > Threshold) { // If the sensor value is above the threshold there might be a fire
    counter++; // Counter for the number of limit value exceedances
    if (counter > counterThreshold) { // If limit value was exceeded, send Warning SMS
      Serial.print("Smoke detected!");
      if (!sent){ // Check if warning SMS was already sent
        GSM.begin(9600);
        sprintf(text, "Sensor Value of %d detected. There is likely a forest fire at location of sensor ID 1.", sensorValue);
        GSM.println("AT"); // Command to wake up SIM_Module
        updateSerial(wt_ms);
        GSM.println("AT+CMGF=1"); // Configuring TEXT mode
        updateSerial(wt_ms);
        GSM.println("AT+CMGS=\""+String(number)+"\"");
        updateSerial(wt_ms);
        GSM.print(text);
        GSM.write(26);
        GSM.println("");
        updateSerial(wt_ms);
        sent = true;
        counter = 0;
      }
    }  
  }
  else if (sensorValue <= Threshold) { // Resets the Counter if the sensor value is again under the threshold value
    counter = 0;
  }
  delay(3000);
}

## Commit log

2023-01-25 Add Arduino Code
2023-01-25 Rename Test_FireDepartment_2023-01-20.csv to Test Data/Test_FireDepartment_2023-01-20.csv
    [Test_FireDepartment_2023-01-20.csv]
2023-01-26 Create 3D-Case
2023-01-26 Rename 3D-Case to 3D-Files Case/Case
